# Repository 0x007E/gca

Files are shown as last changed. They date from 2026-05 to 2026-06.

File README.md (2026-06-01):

  

# `GCA` - Game Card Adapter

The `GCA` is a board with a [AT24CM0X](#additional-information) `EEPROM` or any other compatible `EEPROM`. The board itself can be driven with a voltage from `3V3-5V` and is used chainload games onto the [GamePad](https://github.com/0x007e/gap) over the integrated bootloader (currently under development). 

| Experience  | Level |
|:---|:---:|
| Soldering | ?% |
| Mechanical  | ?% |

# Downloads

| Type | File | Description |
|:---:|:---:|:---|
| Schematic | [pdf](https://github.com/0x007E/gca/releases/latest/download/schematic.pdf) / [cadlab](https://cadlab.io/project/30397/main/files) | Schematic files |
| Board | [pdf](https://github.com/0x007E/gca/releases/latest/download/pcb.pdf) / [cadlab](https://cadlab.io/project/30397/main/files) | Board file |
| Drill | [pdf](https://github.com/0x007E/gca/releases/latest/download/drill.pdf) | Drill file |
| BoM | [xlsx](https://github.com/0x007E/gca/releases/latest/download/bom.xlsx) / [html](https://github.com/0x007E/gca/releases/latest/download/bom.html) | Bill of Material as Excel/interactive HTML |
| PCB | [zip](https://github.com/0x007E/gca/releases/latest/download/kicad.zip) / [tar](https://github.com/0x007E/gca/releases/latest/download/kicad.tar.gz) | KiCAD/Gerber/BoM/Drill files |
| Mechanical | [zip](https://github.com/0x007E/gca/releases/latest/download/freecad.zip) / [tar](https://github.com/0x007E/gca/releases/latest/download/freecad.tar.gz) | FreeCAD/Housing and PCB (STEP/STL) files |

# Hardware

The pcb is created with `KiCAD`, the housing with `FreeCAD`. All files are built with `github actions` so that they are ready for a production environment.

## PCB

The circuit board is populated on both sides (Top, Bottom). The best way for soldering the `SMD` components is within a vapor phase soldering system and for the `THT` components with a standard soldering system.

### Top Layer

Top Layer

### Bottom Layer

Bottom Layer

## Mechanical

The housing has a tolerance of `0.2mm` on each side of the case. So the pcb should fit perfectly in the housing. The tolerance can be modified with `FreeCAD` in the `Parameter` Spreadsheet.

### Assembled

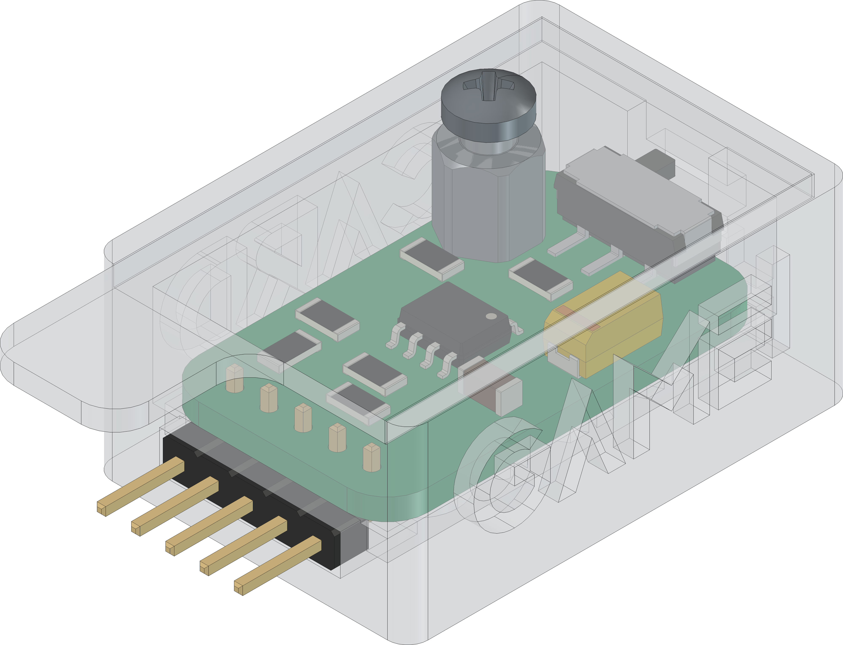
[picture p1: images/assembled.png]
Assembled


### Exploded

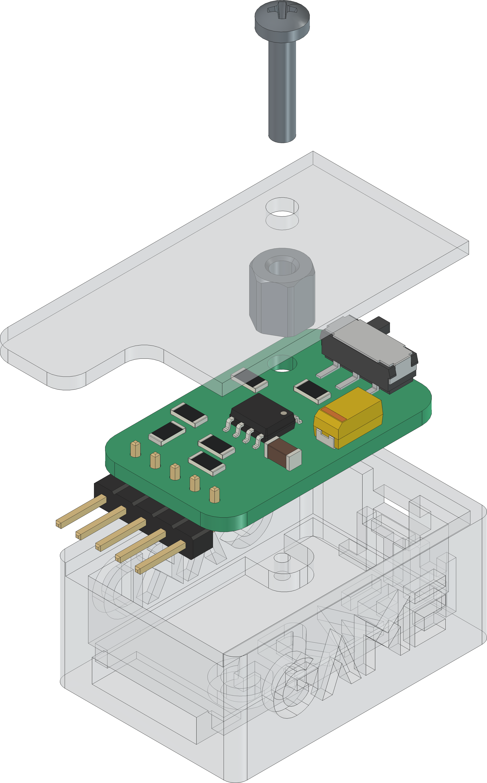
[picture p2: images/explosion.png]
Exploded


# Additional Information

| Type | Link | Description |
|:---:|:---:|:---|
| AT24CM02 | [pdf](https://ww1.microchip.com/downloads/en/DeviceDoc/AT24CM02-I2C-Compatible-Two-Wire-Serial-EEPROM-2-Mbit-262,144x8-20006197C.pdf) | 2-MBit serial EEPROM dataseheet |
| AT24CM01 | [pdf](https://ww1.microchip.com/downloads/en/DeviceDoc/AT24CM01-I2C-Compatible-Two-Wire-Serial-EEPROM-Data-Sheet-20006170A.pdf) | 1-MBit serial EEPROM datasheet |

---

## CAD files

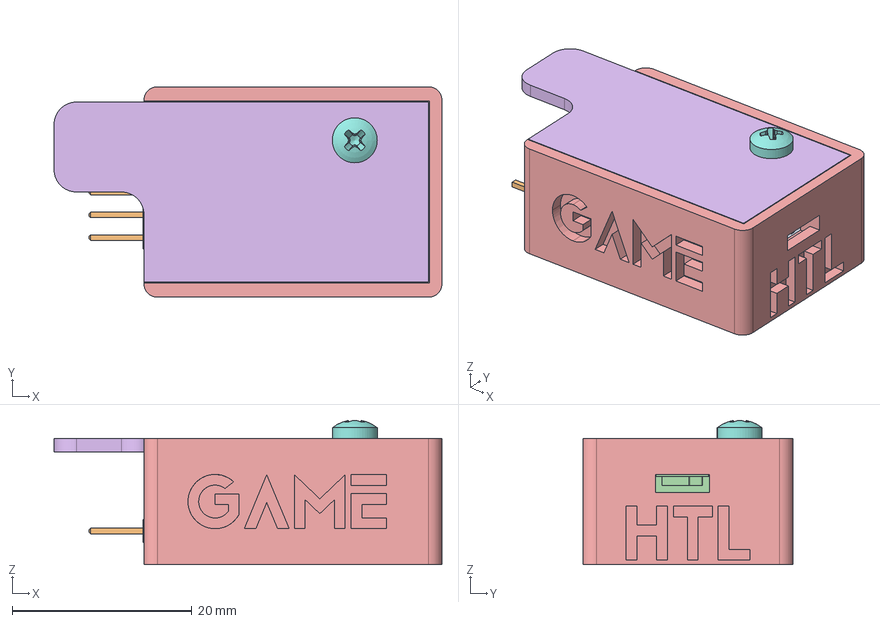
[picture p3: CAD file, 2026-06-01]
mechanical/housing.FCStd
43.1 x 23.4 x 16.0 mm
Pcb_9847
J2_PinHeader_1x05_P254mm_Horizontal_83706f6359c6
U1_SOIC-8_3.9x4.9mm_P1.27mm_eeae3f03861c
SW2_JS102011SAQN_0a465182834c
R4_R_1206_3216Metric_2153681e1708
R1_R_1206_3216Metric_73354968f081
C2_C_1206_3216Metric_2df2ea831409
R3_R_1206_3216Metric_88814e0e38e8
R6_R_1206_3216Metric_b646ac5bb0d1
C1_CP_EIA_6032_28_Kemet_C_caf7d15d7ffa
R2_R_1206_3216Metric_ea23d613c7ea
R5_R_1206_3216Metric_8fba5ca2b483
Case
Acrylglass
M3x6x5.5-Spacer
M2.5x12-Screw

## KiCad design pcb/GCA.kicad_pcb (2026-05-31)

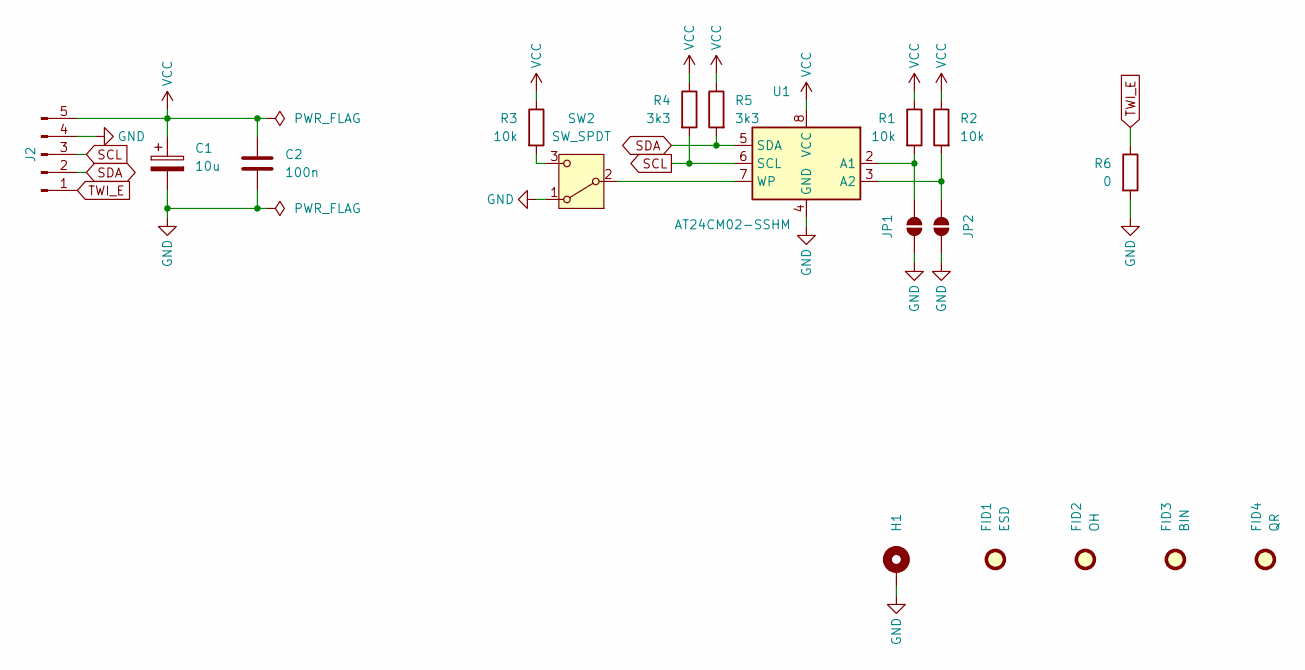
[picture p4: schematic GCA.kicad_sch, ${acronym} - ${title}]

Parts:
C1: 10u; CP_EIA-6032-28_Kemet-C
C2: 100n; C_1206_3216Metric
FID1: ESD; ESD-Logo_6.6x6mm_SilkScreen
FID2: OH; OSHW-Logo_5.7x6mm_SilkScreen
FID3: BIN; WEEE-Logo_4.2x6mm_SilkScreen
FID4: QR; QR_0x007e_very_small
H1: MountingHole_Pad; MountingHole_2.7mm_M2.5_DIN965_Pad
J2: Conn_01x05_Pin; PinHeader_1x05_P2.54mm_Horizontal
JP1, JP2: SolderJumper_2_Open; SolderJumper-2_P1.3mm_Open_RoundedPad1.0x1.5mm
R1, R2, R3: 10k; R_1206_3216Metric
R4, R5: 3k3; R_1206_3216Metric
R6: 0; R_1206_3216Metric
SW2: SW_SPDT; SW_SPDT_CK_JS102011SAQN
U1: AT24CM02-SSHM; SOIC-8_3.9x4.9mm_P1.27mm

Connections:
GND: C1.2, C2.2, H1.1, J2.4, JP1.1 (A), JP2.1 (A), R6.2, SW2.1 (A), U1.4 (GND)
unnamed: JP1.2 (B), R1.2, U1.2 (A1)
unnamed: JP2.2 (B), R2.2, U1.3 (A2)
unnamed: SW2.2 (B), U1.7 (WP)
unnamed: R3.2, SW2.3 (C)
SCL: J2.3, R4.2, U1.6 (SCL)
SDA: J2.2, R5.2, U1.5 (SDA)
TWI_E: J2.1, R6.1
VCC: C1.1, C2.1, J2.5, R1.1, R2.1, R3.1, R4.1, R5.1, U1.8 (VCC)

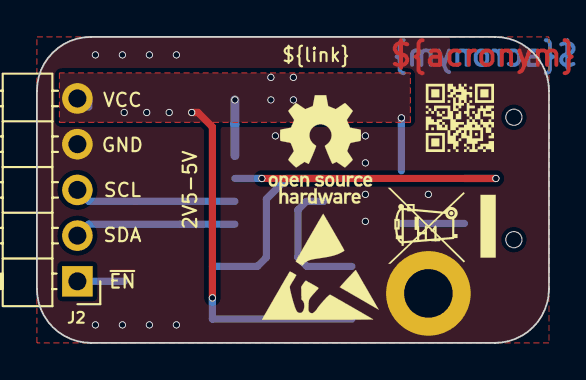
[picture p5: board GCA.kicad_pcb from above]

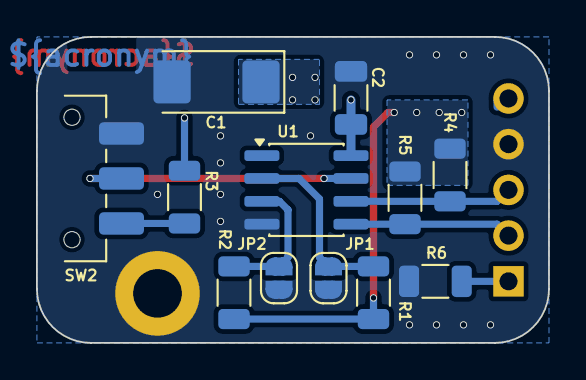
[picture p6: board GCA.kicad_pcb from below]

Board: 2 copper layers, 28.4 x 17.0 mm, 18 parts (12 on the bottom side), 9 nets.

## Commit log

2026-03-11 Add pcb layout
    [GCA.kicad_pcb, GCA.kicad_sch]
2026-04-08 Flip connector to top
    [GCA.kicad_pcb, GCA.kicad_sch]
2026-05-31 Optimize circuit position
    [GCA.kicad_sch]
2026-05-31 Fix fabrication layer view
    [GCA.kicad_pcb]
2026-05-31 Rename/Add/Remove bom fields
    [GCA.kicad_pcb, GCA.kicad_sch]
2026-05-31 Add dimensioning
    [GCA.kicad_pcb]
2026-06-01 Add mechanical parts
    [housing.FCStd]
2026-06-01 Add assembly explosion
    [housing.FCStd]
2026-06-01 Optimize mechanical design
    [housing.FCStd]

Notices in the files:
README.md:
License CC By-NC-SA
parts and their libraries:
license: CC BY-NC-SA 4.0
